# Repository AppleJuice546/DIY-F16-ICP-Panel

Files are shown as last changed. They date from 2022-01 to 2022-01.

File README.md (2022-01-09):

# DIY-F16-ICP-Panel
A simple, budget, DIY F16 ICP flight control panel for use with flight simulators such as DCS World

**PLEASE READ**

This project is still somewhat a work in progress. While the panel is meant to be almost a perfect replica of the real F16 ICP panel, some of the components are not perfect or are unfinished. For example, the rocker switches at the moment are not yet modelled to have any buttons attached. So far, I have modelled the panel as well as a corresponding stand which is designed so that two cougar MFD's can be attached with additional some additional mounts on either side. I plan on modelling these additional mounts soon and will upload them when complete. The intention was so that the MFD's and the ICP can all be attached as one solid unit. 

I have created a bill of materials as well, so please check that out. Hopefully all of the files are not too difficult to print, at least they werent too much trouble for me. 

I have also included a link to the files on Thingiverse below:
https://www.thingiverse.com/thing:5192816

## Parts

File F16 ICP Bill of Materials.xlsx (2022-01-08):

Amount | Item | Description | Link | Price
19 | Mechanical Keyboard Switch | I used Gateron blue switches, used for the 19 major buttons on the panel. | https://www.amazon.com/Mechanical-Keyboards-Black-Shell-Compatible-Light-Pack/dp/B08SCC17T1?s=electronics | $13.99
1 | Teensy 4.0 Board | Used to interface to the computer via USB. | https://www.amazon.com/Teensy-4-0-With-Pins/dp/B08259KDHY?s=electronics | $27.54
4 | 6mm momentary push buttons | used for the rocker switches. Note, my current designs have not yet implemented these, but I plan to finish this in the near future. | https://www.amazon.com/Momentary-Tactile-Through-Breadboard-Friendly/dp/B07WF76VHT | $5.99
4 | RK097N-3-10k Potentiometer | For the four rotary dials on the left and right sides of the panel. It is important to use these exact potentiometers if possible because of the small form factor. It allows the potentiometers not to come into contact with the bottom of the kayboard switches. | https://www.amazon.com/TWTADE-Amplifier-Potentiometers-Knurled-RK097N-3-10K/dp/B07XQ1Q9RN?s=electronics | $12.66
3 | 3 position momentary toggle switch | Used for the three additional switches on the panel. Note, these are not exactly accurate to the real panel, they do not behave like a real dobber switch. For my purposes and for my design however, they work fine. | https://www.amazon.com/Twidec-Momentary-Miniature-Waterproof-MTS-123-MZ/dp/B07VHCB1Q4 | $9.99
4 | M3 x 20mm bolts and nuts | Used for the four corners of the main panel, to sandwich the three pieces to each other. **NOTE** for the nuts and bolts included on this list, I bought one M3 bolt kit from the included Amazon link, which includes both the 20mm and 8mm bolts and nuts. | https://www.amazon.com/DYWISHKEY-Pieces-Button-Screws-Wrench/dp/B07VRC7ZL5 | $9.98
4 | M3 x 8mm bolts and nuts | Used for to connect the rear piece of the panel to the stand, if you choose to go without the stand, these are not necessary. | https://www.amazon.com/DYWISHKEY-Pieces-Button-Screws-Wrench/dp/B07VRC7ZL5
1 | 22AWG 10ft wire spool | The wire size really doesnt matter all too much here, I just bought a pack of different colored spools from amazon. If you are looking to buy something else, I would recommend about 10ft of wire. This should give you some nice leeway. | https://www.amazon.com/22AWG-Silicone-OD-Stranded-Insulation/dp/B07T4SYVYG | $13.99
 |  |  |  | $94.14
 |  | **NOTE** Much of what I purchased was bought in bulk, as I like to have extras for other projects. If needed, you could probably cut the cost down even further with the bare minimum quantity of materials.

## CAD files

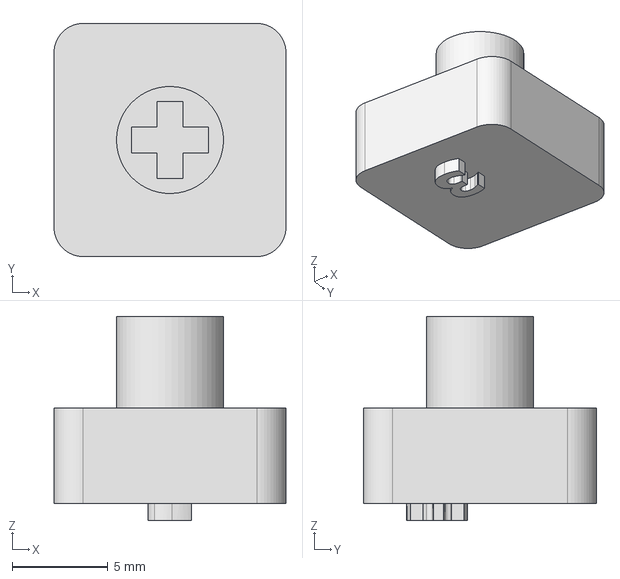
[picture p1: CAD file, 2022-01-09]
STEP FILES/IPC 3 key.stp
12.1 x 12.2 x 10.7 mm

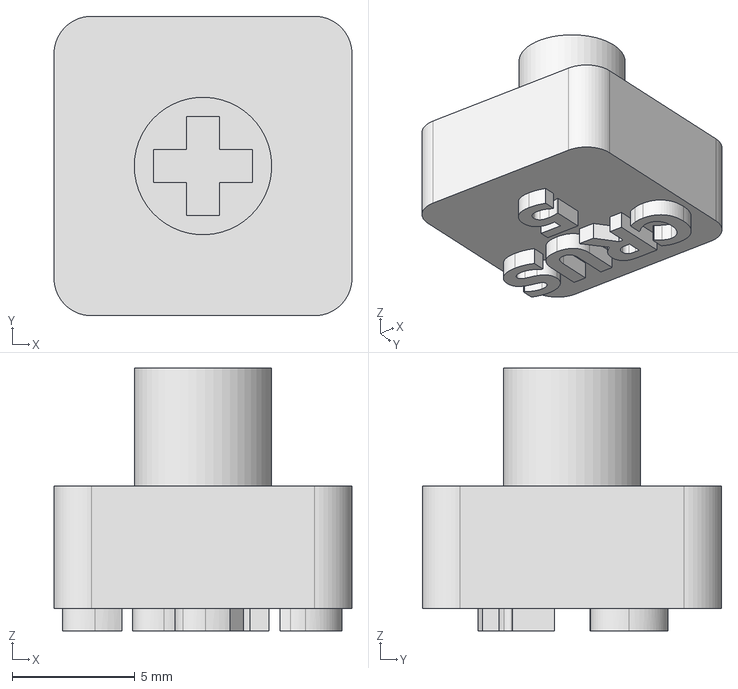
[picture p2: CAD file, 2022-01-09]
STEP FILES/IPC CRUS 5 key.stp
12.1 x 12.2 x 10.7 mm

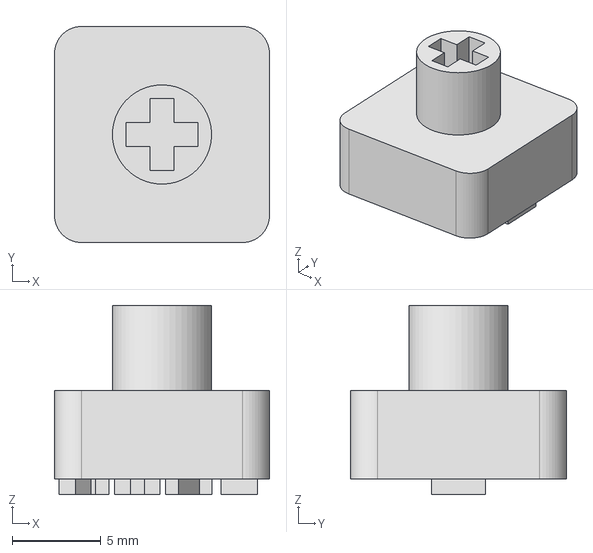
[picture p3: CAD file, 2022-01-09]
STEP FILES/IPC ENTR key.stp
12.1 x 12.2 x 10.7 mm

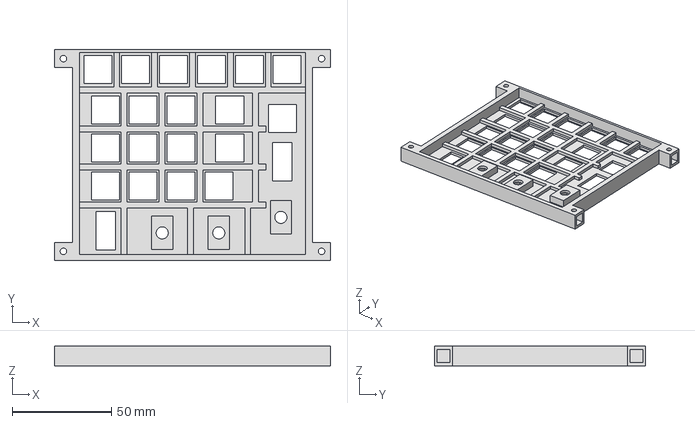
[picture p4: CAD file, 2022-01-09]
STEP FILES/IPC Component Panel.stp
138.9 x 106.0 x 10.0 mm

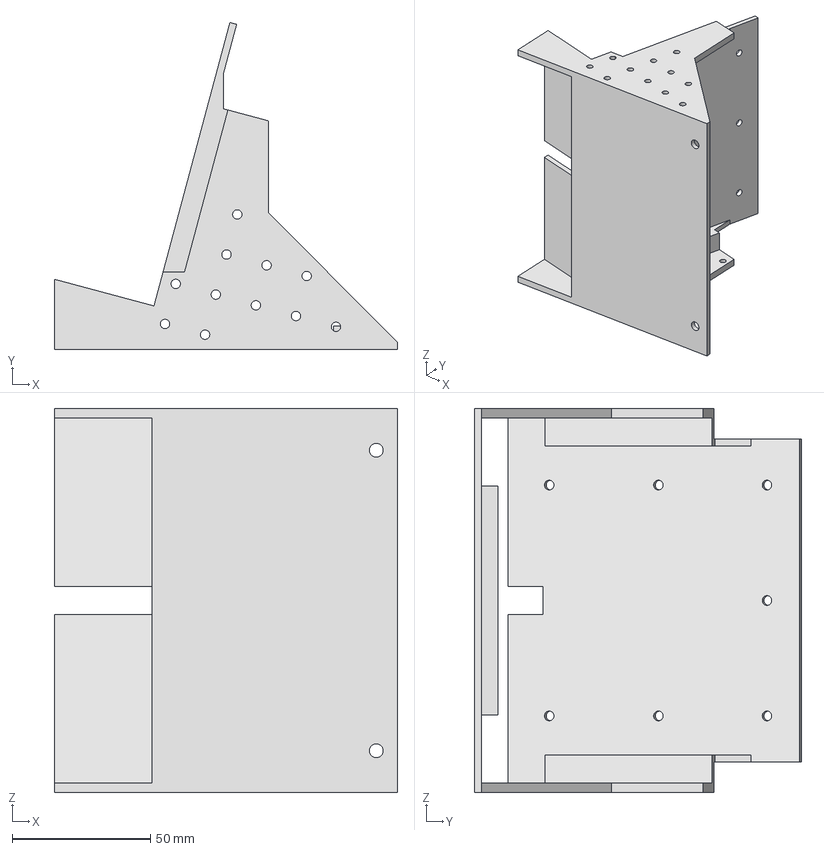
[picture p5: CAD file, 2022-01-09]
STEP FILES/IPC Modular Stand.stp
124.2 x 118.2 x 138.8 mm

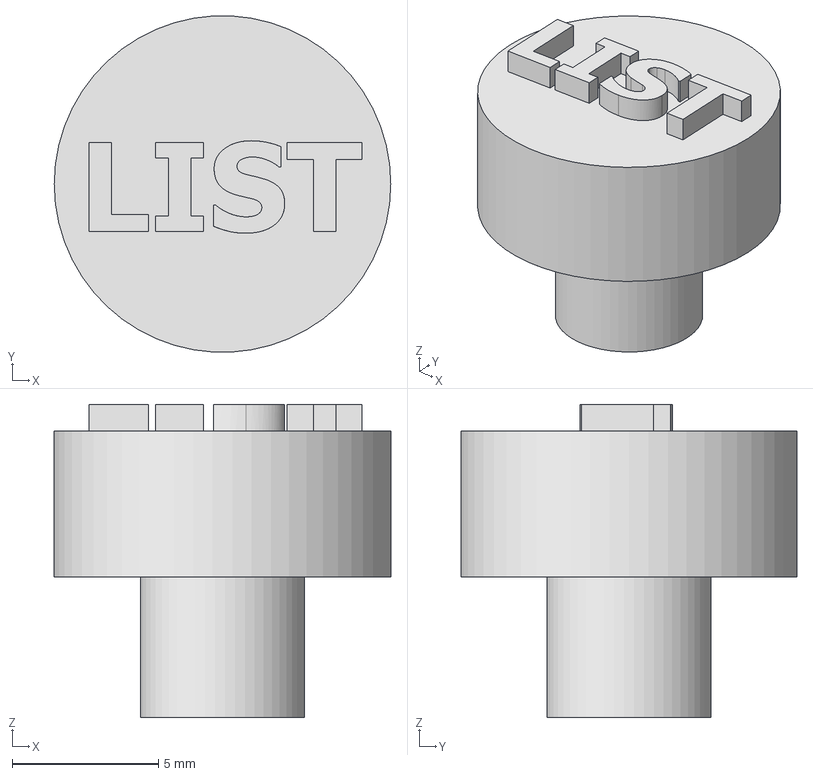
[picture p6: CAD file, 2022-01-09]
STEP FILES/IPC List key.stp
11.5 x 11.5 x 10.7 mm

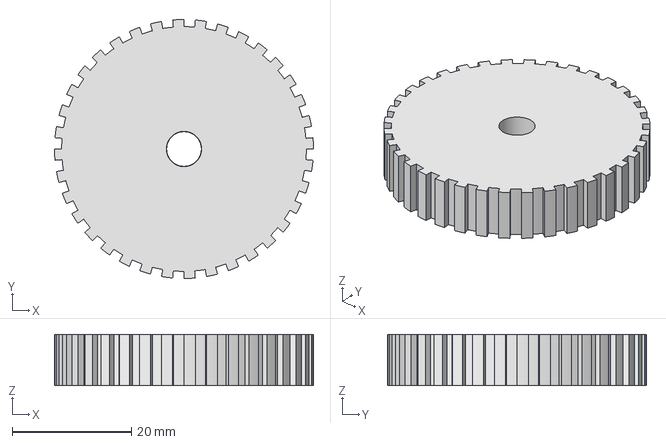
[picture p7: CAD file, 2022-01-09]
STEP FILES/IPC BRT Knob.stp
43.4 x 43.4 x 8.60 mm

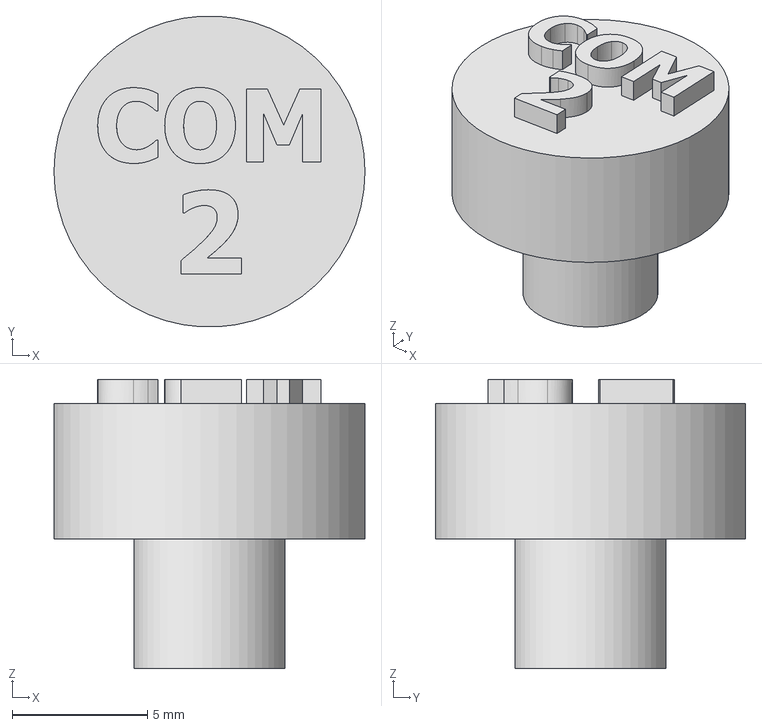
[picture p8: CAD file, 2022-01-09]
STEP FILES/IPC Com 2 key.stp
11.5 x 11.5 x 10.7 mm

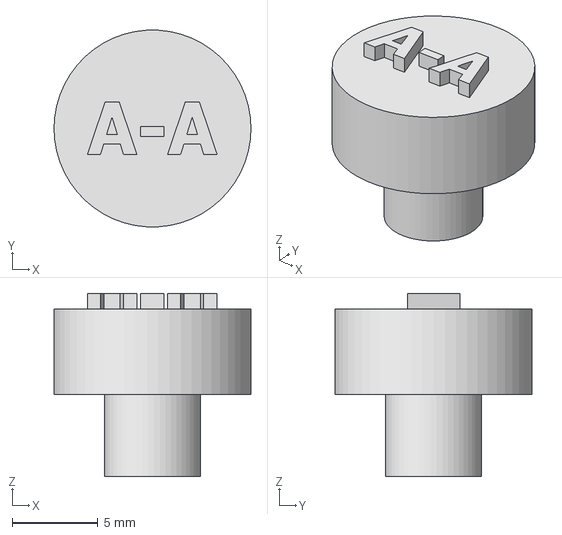
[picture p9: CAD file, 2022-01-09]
STEP FILES/IPC A-A key.stp
11.5 x 11.5 x 10.7 mm

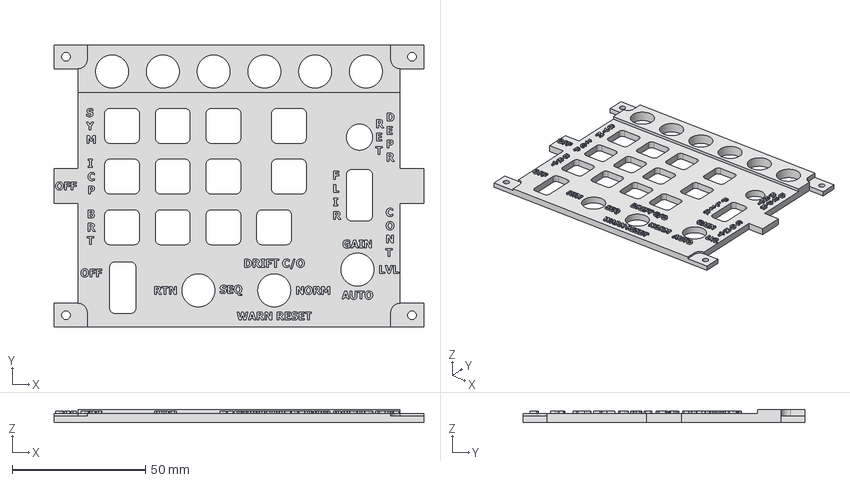
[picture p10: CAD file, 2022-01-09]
STEP FILES/IPC Front Panel.stp
138.9 x 106.0 x 5.00 mm

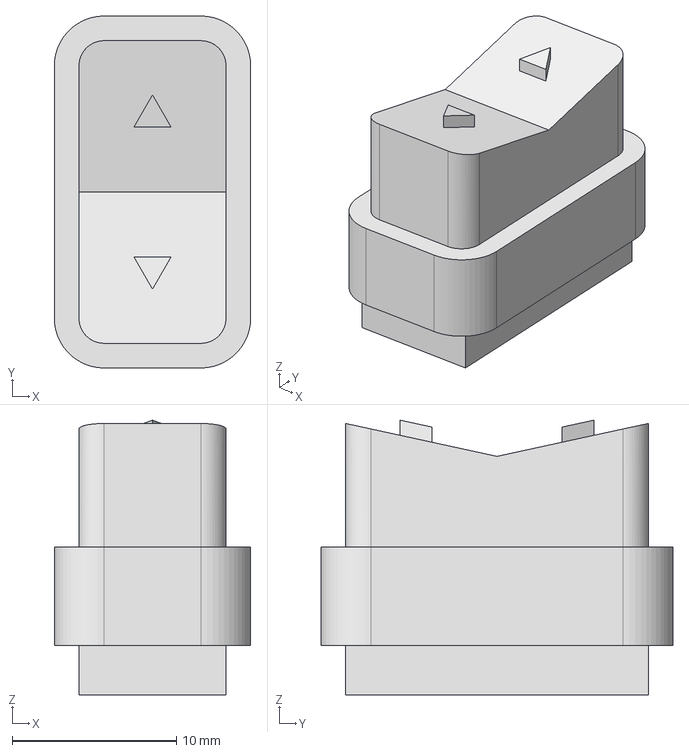
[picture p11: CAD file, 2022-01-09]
STEP FILES/IPC dumb rocker switch.stp
11.9 x 21.4 x 16.7 mm

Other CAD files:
STEP FILES/IPC A-CAL 9 key.stp
STEP FILES/IPC M-SEL 0 key.stp
STEP FILES/IPC ALOW 2 key.stp
STEP FILES/IPC MARK 7 key.stp
STEP FILES/IPC STPT 4 key.stp
STEP FILES/IPC TILS 1 key.stp
STEP FILES/IPC TIME 6 key.stp
INVENTOR .IPT FILES/IPC 3 key.ipt
INVENTOR .IPT FILES/IPC A-A key.ipt
INVENTOR .IPT FILES/IPC A-CAL 9 key.ipt
INVENTOR .IPT FILES/IPC A-G key.ipt
INVENTOR .IPT FILES/IPC ALOW 2 key.ipt
INVENTOR .IPT FILES/IPC BRT Knob.ipt
INVENTOR .IPT FILES/IPC CRUS 5 key.ipt
INVENTOR .IPT FILES/IPC Com 1 key.ipt
INVENTOR .IPT FILES/IPC Com 2 key.ipt
INVENTOR .IPT FILES/IPC Component Panel.ipt
INVENTOR .IPT FILES/IPC ENTR key.ipt
INVENTOR .IPT FILES/IPC FIX 8.ipt
INVENTOR .IPT FILES/IPC Front Panel.ipt
INVENTOR .IPT FILES/IPC IFF.ipt
INVENTOR .IPT FILES/IPC List key.ipt
INVENTOR .IPT FILES/IPC M-SEL 0 key.ipt
INVENTOR .IPT FILES/IPC MARK 7 key.ipt
INVENTOR .IPT FILES/IPC Modular Stand.ipt
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

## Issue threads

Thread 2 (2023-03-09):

STL file for the component panel doesn't match the IPT file

BenJonesMakers, 2023-03-09:
Hi.  Just a heads up. I was actually coming here to grab the files so I could make the change to add the switch box but when I looked at the IPT file it already had it so that saved me a job but you might want to update the STL files on thingiverse.

Great work btw 👍
